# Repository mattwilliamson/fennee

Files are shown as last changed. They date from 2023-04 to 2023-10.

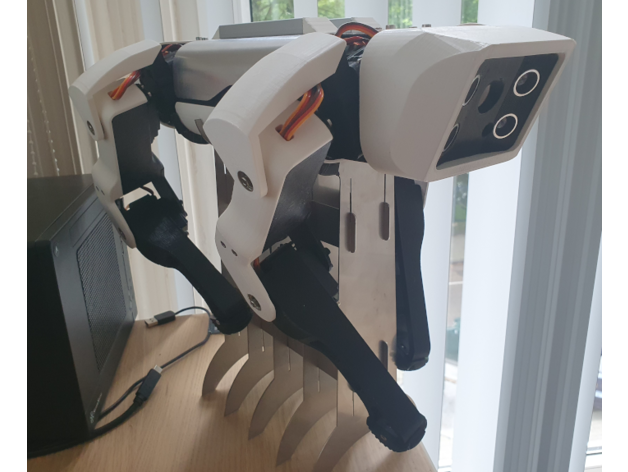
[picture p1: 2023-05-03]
models/SpotMicroESP32_with_reinforced_shoulders_4937631/images/featured_preview_saddled_with_shoulders.png

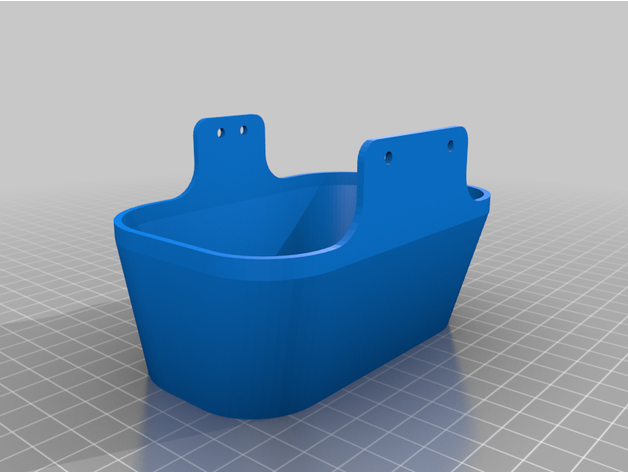
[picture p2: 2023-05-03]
models/SpotMicroESP32_with_reinforced_shoulders_4937631/images/Rear_Cover_Shell_Medium.png

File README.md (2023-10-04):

# Fennee Quadruped Robot

**F**oundation for **E**xperimental **N**eural **N**etwork **E**ndeavors

### Printing Video
Printing Fennee (http://www.youtube.com/watch?v=NxGy5EySv1w "Printing Fennee")

### Walking video
Fennee on the Run (http://www.youtube.com/watch?v=MeTuUr-WjSU "Fennee on the run")

---

# Hardware
Check the [Hardware & Parts Details docs](./docs/hardware.md)

# Software

- [Champ](https://github.com/chvmp/champ)
- [Ubuntu 20.04 Jetson Image](https://github.com/Qengineering/Jetson-Nano-Ubuntu-20-image) flashed on SD card with [Balena Etcher](https://www.balena.io/etcher)
- [ROS 1 Noetic](http://wiki.ros.org/noetic/Installation/Ubuntu)
- [Adafruit CircuitPython libraries](https://docs.circuitpython.org/projects/bundle/en/latest/drivers.html)
- [LDS-01 LIDAR ROS Driver](http://wiki.ros.org/hls_lfcd_lds_driver)

## Install Fennee Packages

First [Install ROS Noetic](./docs/install_ros.md)

**I'd like to switch to ROS2 when CHAMP finishes porting over**

```sh
# Source your ROS installation
source /opt/ros/noetic/setup.bash

# CD to your workspace source, e.g. ~/ros_ws and clone the repo
mkdir -p ~/ros_ws/src
cd ~/ros_ws/src
git clone https://github.com/mattwilliamson/fennee.git
vcs import < fennee/fennee_ros/fennee.rosinstall --recursive

# CD to your workspace and build
cd ..
rosdep install --from-paths src --ignore-src -r -y
catkin_make

# Source your build
source devel/setup.bash
```

## Running

TODO: Need to specify dependencies correctly

```sh

sudo pip3 install -t /opt/ros/noetic/lib/python3/dist-packages adafruit_blinka adafruit-circuitpython-servokit pyyaml
```

### Simulator

```sh
source devel/setup.bash
roslaunch fennee_config bringup.launch rviz:=true
```

```sh
source devel/setup.bash
roslaunch champ_teleop teleop.launch joy:=true
```

With a PS4/DS4 controller:

| Input | Output |
| --- | --- |
| Left Stick  | Walk/Yaw |
| Right Stick | Pitch/Roll |
| L1 (hold) | Holonomic (strafing) |
| R2 | Sit |

### Jetson Nano
```sh
ssh user@jetson
mkdir -p ~/ros_ws/src
cd ~/ros_ws/src

git clone https://github.com/mattwilliamson/fennee.git
cd fennee

sudo docker build -t fennee .
sudo docker run -it --rm --runtime nvidia --network host fennee
sudo docker run -it --rm --runtime nvidia -v $HOME/ros_ws/src/fennee:/fennee_ws/src/fennee --network host fennee

# Source your build
source devel/setup.bash
roslaunch fennee_config bringup.launch hardware_connected:=true
```

### Hardware

```sh
roslaunch fennee_config bringup.launch hardware_connected:=true

roslaunch champ_teleop teleop.launch joy:=true

rostopic echo joint_states
```

```sh
roslaunch fennee_config bringup.launch hardware_connected:=true
```

### Calibration

Start up a terminal GUI to set the servo offsets to a yaml file

```
roslaunch fennee_control servo_interface.launch calibrate:=true
```

```
rostopic echo servo_duty_cycles
```

Put duty cycles into `fennee_control/scripts/servo_interface.py` `pwm_map`.

fennee_config/config/gait/gait.yaml has `com_x_translation` to shift the center of balance from the front to the back. 
For example `-0.01` if the robot is leaning backwards a bit, keeping it from walking.

### Watching logs

GUI

```
rqt_console
```

### Credits
https://github.com/chvmp
https://github.com/michaelkubina/SpotMicroESP32
https://spotmicroai.readthedocs.io/en/latest/
https://www.thingiverse.com/thing:4937631

## TODO

- [ ] rewrite IMU in c++
- [ ] Make calibration launch file and parse yaml for servo_controller
- [ ] Calibration script docs
- [x] Update URDF with longer body
- [ ] Package requirements are a mess. pip vs rosdep etc.
- [ ] Charging connector
- [ ] Add clips to battery clips for wires
- [ ] Rear cover hole for voltmeter
- [x] Oak D Lite Camera mount
- [ ] LED Ring sticking out under lidar?
- [x] Separate mount for IMU
- [ ] Supports around holes for covers
- [x] Custom top and bottom cover, speakers, mic, fan
- [x] Lengthen chassis for more electronics room
- [x] Removable electronicts mount
- [x] Custom hip for metal servo arm
- [x] Custom mounting board for electronics
- [x] Custom nose for camera and LED ring
- [x] Lengthen body
- [x] New cover with lidar mount and fan
- [x] Front camera
- [ ] IMU Publisher
- [x] Faster baud rate
- [ ] Calibration config file
- [ ] Wiring diagrams
- [ ] 3d print instructions/list
- [ ] Show loading screen while robot is waiting for ROS
- [ ] LED ring
- [x] LIDAR
- [ ] Relay for servos
- [ ] Some kind of quick release for covers - removing battery is annoying
- [ ] Speakers/mic
- [ ] blacklist packages: ros-noetic-rosserial ros-noetic-rviz ros-noetic-gazebo-plugins

---

# Docker

https://hub.docker.com/_/ros/

Building the image
`LOW_MEM` is for lower memory systems, but takes longer.

```sh
sudo docker build --build-arg LOW_MEM=1 -t fennee .
```

ROS uses the ~/.ros/ directory for storing logs, and debugging info
```sh
docker run -v "/home/ubuntu/.ros/:/root/.ros/" -it --rm --network=host fennee
```

```sh
sudo docker run --rm -it -e ROS_IP=192.168.50.83 --privileged -v /dev/:/dev/ --network host fennee roslaunch fennee_config bringup.launch hardware_connected:=true
```

RViz/Gazebo
```sh
sudo docker run --rm -it -v /dev/:/dev/ --network host -e DISPLAY -v /tmp/.X11-unix:/tmp/.X11-unix --privileged depthai_ros roslaunch depthai_filters example_seg_overlay.launch
```

Camera publisher with overlay for object detection
```sh
sudo docker run --rm -it -e ROS_IP=192.168.50.83 --privileged -v /dev/:/dev/ --network host fennee roslaunch depthai_filters example_det2d_overlay.launch camera_model:=OAK-D-LITE
```

Camera publisher with stereo, RGB and IMU
```sh
sudo docker run --rm -it -e ROS_IP=192.168.50.83 --privileged -v /dev/:/dev/ --network host fennee roslaunch depthai_examples stereo_inertial_node.launch enableRviz:=false
```

View Camera
```sh
ROS_MASTER_URI=http://192.168.50.83:11311
rqt_image_view
```

Record Video to output.avi
```sh
fennee
ROS_MASTER_URI=http://192.168.50.83:11311 rosrun image_view video_recorder image:=/mobilenet_publisher/color/image
vlc output.avi
```

Mapping
```sh
ROS_MASTER_URI=http://192.168.50.83:11311
roslaunch fennee_config slam.launch rviz:=true  
```

Save map
```sh
roscd fennee_config/maps
rosrun map_server map_saver
```

Autonomous Navigation
```sh
roslaunch fennee_config navigate.launch rviz:=true
```

roslaunch champ_config slam.launch rviz:=true

roslaunch fennee_config navigate.launch

# PS4 Controller
*hold PS button and share button*

```
bluetoothctl
scan on
[NEW] Device A4:AE:12:BA:36:63 Wireless Controller

pair A4:AE:12:BA:36:63
trust A4:AE:12:BA:36:63
```

```sh
roslaunch fennee_config bringup.launch hardware_connected:=true
# roslaunch fennee_config bringup.launch hardware_connected:=true servo_connected:=false
roslaunch champ_teleop teleop.launch joy:=true
```

# IMU
http://docs.ros.org/en/melodic/api/robot_localization/html/preparing_sensor_data.html

sensor_msgs/Imu - The IMU message is currently subject to some ambiguity, though this is being addressed by the ROS community. Most IMUs natively report orientation data in a world-fixed frame whose axes are defined by the vectors pointing to magnetic north and the center of the earth, respectively, with the Y axis facing east (90 degrees offset from the magnetic north vector). This frame is often referred to as NED (North, East, Down). However, REP-103 specifies an ENU (East, North, Up) coordinate frame for outdoor navigation. As of this writing, robot_localization assumes an ENU frame for all IMU data, and does not work with NED frame data. This may change in the future, but for now, users should ensure that data is transformed to the ENU frame before using it with any node in robot_localization.

Measure +9.81
 meters per second squared for the Z
 axis.
If the sensor is rolled +90
 degrees (left side up), the acceleration should be +9.81
 meters per second squared for the Y
 axis.
If the sensor is pitched +90
 degrees (front side down), it should read -9.81
 meters per second squared for the X
 axis.

 The IMU may also be oriented on the robot in a position other than its “neutral” position. For example, the user may mount the IMU on its side, or rotate it so that it faces a direction other than the front of the robot. This offset is typically specified by a static transform from the base_link_frame parameter to the IMU message’s frame_id. The state estimation nodes in robot_localization will automatically correct for the orientation of the sensor so that its data aligns with the frame specified by the base_link_frame parameter.

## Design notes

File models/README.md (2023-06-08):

# 3d Printing Models
I printed everything in PETG except the feet in TPU

# michaelkubina_SpotMicroESP32
This is the primary source of parts. I customized some of these and found some customized ones.

# Outer_Shoulder_round_servohorn
The hip servohorn broke several times, so I updated the model to accept a round, metal servohorn.

# Chassis_Side_longer
Lengthened the body 25mm to accomodate a Jetson Nano and a larger buck converter.

# Circuitry_Mountingplate_jetson_nano

# metaldisc_servohorn_mod
under mods

# SpotMicroESP32_with_reinforced_shoulders_4937631
Reinforced shoulders by Rob Knegjens

Replaces a couple parts from SpotMicroESP32

Summary from Thingiverse https://www.thingiverse.com/thing:4937631

## Summary
This is a remix of Michael Kubina's SpotMicroESP32. It adds a reinforced shoulder joint cover as well as a shorter rear cover and back plate.

For the original SpotMicro the limbs connect to the shoulders only via the servo shaft, which in my experience made for a flimsy/wobbly joint. Reinforcing the joint with an extended shoulder attached to ball bearings on the outer limb improves this considerably.

My shoulder cover design was inspired by the Parametric Shoulder Joint for SpotMicroESP32 from projunk. Notable features are:

Uses 625ZZ ball bearings (as for the original).
The Shoulder Cover attaches to the extended Servo Cap using 3x20 mm screws and M3 nuts (as used by original build).
Hidden screw and nut holes on shoulder cover for a smooth look.
Prints support free.
The new medium rear cover is a shortened version of the long rear cover of the original build. The 3x8mm screws attaching the back plate are now rear facing. The back plate has cut-out inserts for a SSD1306 OLED screen and two GX16 connectors.

The spot shown in the photos has an aluminium top cover with mounting rails. This was made by Thomas Van Der Sterren.

## Print Settings
### Printer brand:
Creality

### Printer:
Ender 3 Pro

### Rafts:
No
### Supports:
No
### Resolution:
0.2 mm
### Infill:
20
### Filament brand:
REAL

### Filament color:
Black, White

### Filament material:
PLA, TPU

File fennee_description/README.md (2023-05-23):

# fennee_description

A minimal and revamped version of [SpotmicroAI](https://spotmicroai.readthedocs.io/en/latest/) description file pulled from its [Gitlab](https://gitlab.com/custom_robots/spotmicroai/simulation) repository.

The meshes' path have been modified so the models can be located using its package name.

## Quick Start

You can view the model by running:

    roslaunch fennee_description view_urdf.launch

## Testing

You can modify the Xacro description and see the changes in the UDF file with this command:

    rosrun xacro xacro fennee.urdf.xacro > fennee.urdf

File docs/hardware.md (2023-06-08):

# Hardware

## Parts List

- [SpotMicro](https://spotmicroai.readthedocs.io/en/latest/) robot frame
- [NVIDIA Jetson Nano](https://www.amazon.com/NVIDIA-Jetson-Nano-Developer-945-13450-0000-100/dp/B084DSDDLT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) for high-level control
- [SD Card](https://www.amazon.com/dp/B07FCMBLV6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)
- LDS-01 LIDAR
- USB TTL converter for LIDAR
- PCA9685 PWM controller for controlling servos: https://www.adafruit.com/product/815
- 12x [DS3218 Digital Servo Motor](https://www.amazon.com/gp/product/B07WYQ9P3F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)
- [LiPO Battery](https://www.amazon.com/dp/B086D71TZC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) this one is 5200mAh 7.4v, but you have flexibility here
- [Buck Converter](https://www.amazon.com/dp/B07Y7YB14L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)
- 2x [Bearings](https://www.amazon.com/dp/B07JHKKGKT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)
- [Lots](https://www.amazon.com/dp/B015A30R1I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) of [m3 screws and nuts (some m2 as well)](https://www.amazon.com/dp/B08JCKH31Q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)
- [PETG Filament](https://www.amazon.com/dp/B08JCKH31Q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)

*Disclaimer: I did add Amazon affiliate links to these*

### Optional

- [Waveshare AC8265](https://www.amazon.com/dp/B07SGDRG34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) WiFi and Bluetooth for Jetson Nano
- [IPEX Wifi Antennas](https://www.amazon.com/Antenna-2-4GHz-Internal-Laptop-Wireless/dp/B08XN6WMXJ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)
- [Volt Display](https://www.amazon.com/dp/B0761MG9NS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)
- [Creality Ender 3 S1 Pro 3d printer](https://www.amazon.com/3D-High-Temperature-Removable-Touchscreen-Languages/dp/B09TKCY9HY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)

## 3d Printed

- [SpotMicro prints without supports](https://www.thingiverse.com/thing:4559827)
- [Reinforced shoulders](https://www.thingiverse.com/thing:4937631)
- [Assembly Guide](https://github.com/mattwilliamson/SpotMicroESP32/tree/master/assembly) *Needs some updates*

---

## TODO Documentation

- [ ] Lidar specs - LDS-01 - https://emanual.robotis.com/docs/en/platform/turtlebot3/appendix_lds_01/ - https://medium.com/@Matthew_Hogan/interesting-electronic-components-1-hls-lfcd2-640d897f9fc9
- [ ] Oak D Lite - needs right angle cable

---

PCA9685 Connection
 - Connect VCC Pin of PCA9685 to 3.3 Volt Pin of Jetson Nano (Pin 1 upper outside)
 - Connect GND Pin of PCA9685 to Jetson Nano GND (Row 3, inside pin)
 - Connect SDA Pin of PCA9685 to Jetson Nano Pin 3 (Row 2, outside pin)
 - Connect SCL Pin of PCA9685 to Jetson Nano Pin 5 (Row 3, outside pin)

```
jetson@fennee:~/ros_ws$ sudo i2cdetect -y -r 1
     0  1  2  3  4  5  6  7  8  9  a  b  c  d  e  f
00:          -- -- -- -- -- -- -- -- -- -- -- -- -- 
10: -- -- -- -- -- -- -- -- -- -- -- -- -- -- -- -- 
20: -- -- -- -- -- -- -- -- -- -- -- -- -- -- -- -- 
30: -- -- -- -- -- -- -- -- -- -- -- -- -- -- -- -- 
40: 40 -- -- -- -- -- -- -- -- -- -- -- -- -- -- -- 
50: -- -- -- -- -- -- -- -- -- -- -- -- -- -- -- -- 
60: -- -- -- -- -- -- -- -- -- -- -- -- -- -- -- -- 
70: 70 -- -- -- -- -- -- --             
```

---

BNO085 IMU Connection

If you solder a header on the opposite side of the PCA9685, you can just daisy-chain onto that same I2C bus.

```
jetson@fennee:~/ros_ws/src/fennee$ i2cdetect -r -y 1
     0  1  2  3  4  5  6  7  8  9  a  b  c  d  e  f
00:          -- -- -- -- -- -- -- -- -- -- -- -- -- 
10: -- -- -- -- -- -- -- -- -- -- -- -- -- -- -- -- 
20: -- -- -- -- -- -- -- -- -- -- -- -- -- -- -- -- 
30: -- -- -- -- -- -- -- -- -- -- -- -- -- -- -- -- 
40: 40 -- -- -- -- -- -- -- -- -- -- 4b -- -- -- -- 
50: -- -- -- -- -- -- -- -- -- -- -- -- -- -- -- -- 
60: -- -- -- -- -- -- -- -- -- -- -- -- -- -- -- -- 
70: 70 -- -- -- -- -- -- --       
```

For mine, the address was 0x4b.

Testing:

```
$ sudo pip3 install adafruit-circuitpython-bno08x

$ python3
import board
import busio
import time
import adafruit_bno08x
from adafruit_bno08x.i2c import BNO08X_I2C
i2c = busio.I2C(board.SCL, board.SDA)
i2c.scan()
#bno = BNO08X_I2C(i2c)
bno = BNO08X_I2C(i2c, address=0x4b)
bno.enable_feature(BNO_REPORT_ACCELEROMETER)
bno.enable_feature(BNO_REPORT_GYROSCOPE)
bno.enable_feature(BNO_REPORT_MAGNETOMETER)
bno.enable_feature(BNO_REPORT_ROTATION_VECTOR)
while True:
     time.sleep(0.5)
     print("Acceleration:")
     accel_x, accel_y, accel_z = bno.acceleration  # pylint:disable=no-member
     print("X: %0.6f  Y: %0.6f Z: %0.6f  m/s^2" % (accel_x, accel_y, accel_z))
     print("")
     #
     print("Gyro:")
     gyro_x, gyro_y, gyro_z = bno.gyro  # pylint:disable=no-member
     print("X: %0.6f  Y: %0.6f Z: %0.6f rads/s" % (gyro_x, gyro_y, gyro_z))
     print("")
     #
     print("Magnetometer:")
     mag_x, mag_y, mag_z = bno.magnetic  # pylint:disable=no-member
     print("X: %0.6f  Y: %0.6f Z: %0.6f uT" % (mag_x, mag_y, mag_z))
     print("")
     #
     print("Rotation Vector Quaternion:")
     quat_i, quat_j, quat_k, quat_real = bno.quaternion  # pylint:disable=no-member
     print(
      "I: %0.6f  J: %0.6f K: %0.6f  Real: %0.6f" % (quat_i, quat_j, quat_k, quat_real)
     )
     print("")
```

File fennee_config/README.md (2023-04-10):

## 1. Quick Start

You don't need a physical robot to run the following demos. 

### 1.1. Walking demo in RVIZ:

#### 1.1.1. Run the base driver:

    roslaunch fennee_config bringup.launch rviz:=true

#### 1.1.2. Run the teleop node:

    roslaunch champ_teleop teleop.launch

If you want to use a [joystick](https://www.logitechg.com/en-hk/products/gamepads/f710-wireless-gamepad.html) add joy:=true as an argument.

### 1.2. SLAM demo:

#### 1.2.1. Run the Gazebo environment:

    roslaunch fennee_config gazebo.launch 

#### 1.2.2. Run gmapping package and move_base:

    roslaunch fennee_config slam.launch rviz:=true

To start mapping:

- Click '2D Nav Goal'.
- Click and drag at the position you want the robot to go.

   champ

- Save the map by running:

      roscd fennee_config/maps
      rosrun map_server map_saver

### 1.3. Autonomous Navigation:

#### 1.3.1. Run the Gazebo environment: 

    roslaunch fennee_config gazebo.launch 

#### 1.3.2. Run amcl and move_base:

    roslaunch fennee_config navigate.launch rviz:=true

To navigate:

- Click '2D Nav Goal'.
- Click and drag at the position you want the robot to go.

   champ

#### 1.4.1 Spawning multiple robots in Gazebo

Run Gazebo and default simulation world:

    roslaunch champ_gazebo spawn_world.launch 

You can also load your own world file by passing your world's path to 'gazebo_world' argument:

    roslaunch champ_gazebo spawn_world.launch gazebo_world:=<path_to_world_file>

Spawning a robot:

    roslaunch fennee_config spawn_robot.launch robot_name:=<unique_robot_name> world_init_x:=<x_position> world_init_y:=<y_position>

* Every instance of the spawned robot must have a unique robot name to prevent the topics and transforms from clashing.

---
:exclamation: *This is not an official product from the robot's company/author.*

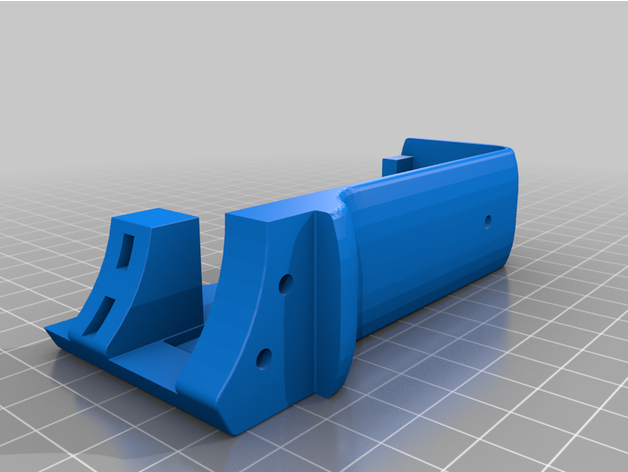
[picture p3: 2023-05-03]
models/SpotMicroESP32_with_reinforced_shoulders_4937631/images/Limb_Top_Shell_with_BB_hole.png

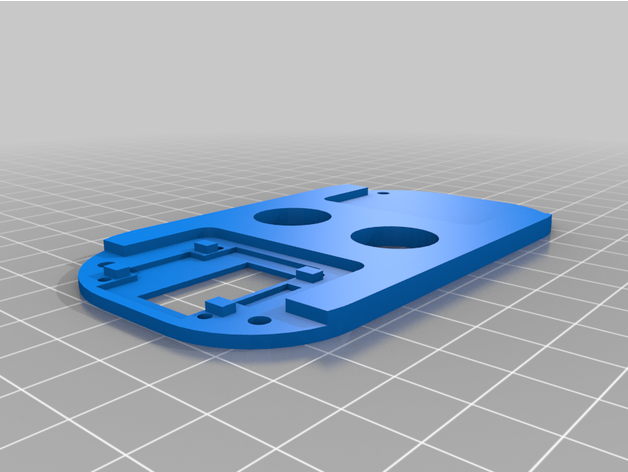
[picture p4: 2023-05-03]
models/SpotMicroESP32_with_reinforced_shoulders_4937631/images/Rear_Cover_Plate_Medium.png

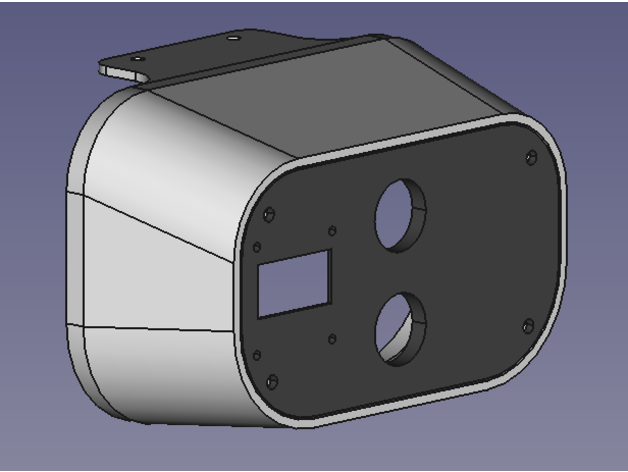
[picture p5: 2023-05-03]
models/SpotMicroESP32_with_reinforced_shoulders_4937631/images/featured_preview_RearCAD2.png

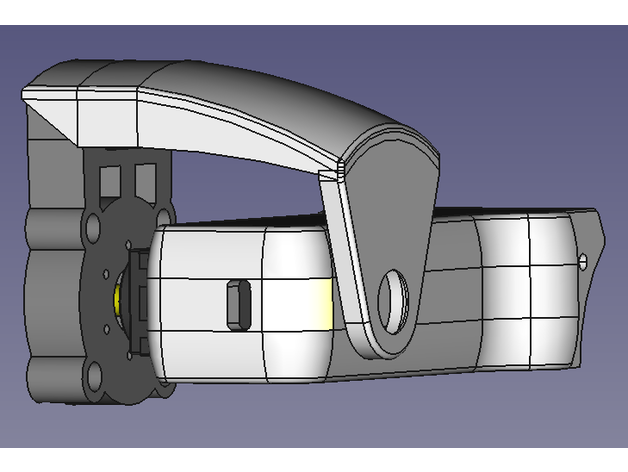
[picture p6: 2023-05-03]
models/SpotMicroESP32_with_reinforced_shoulders_4937631/images/featured_preview_ShoulderCAD1.png

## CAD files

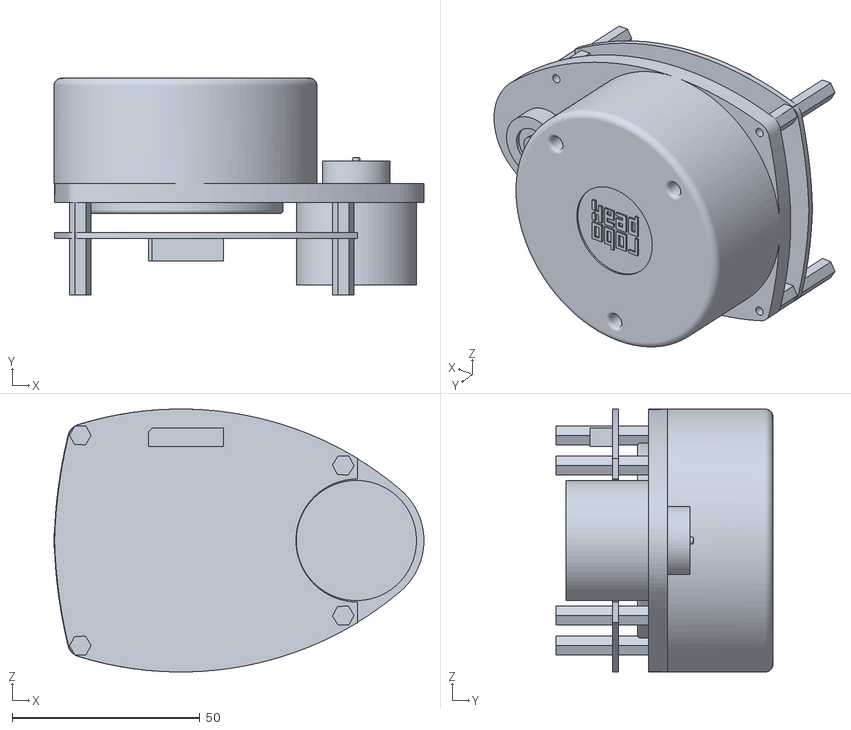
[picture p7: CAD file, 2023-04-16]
fennee_description/meshes/stl/rplidar_main.STL
98.5 x 57.7 x 70.0

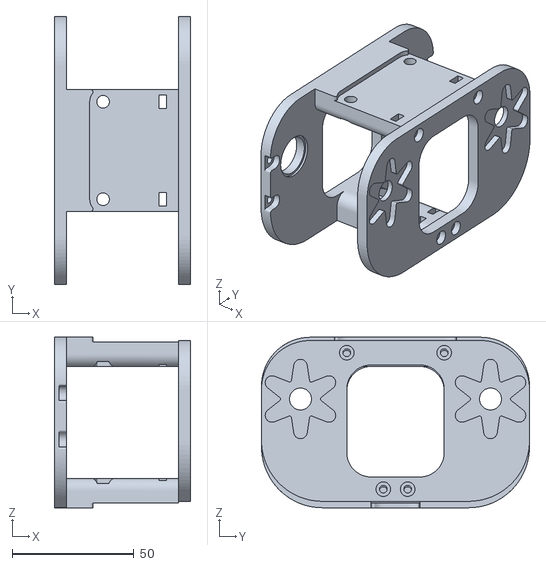
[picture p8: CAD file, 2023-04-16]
fennee_description/meshes/stl/rearmain.stl
55.9 x 110.0 x 70.0

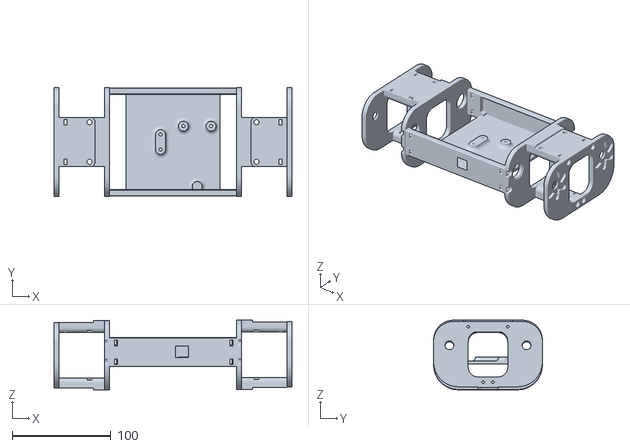
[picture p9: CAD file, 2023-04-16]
fennee_description/meshes/stl/mainbody.stl
240.7 x 110.0 x 70.4

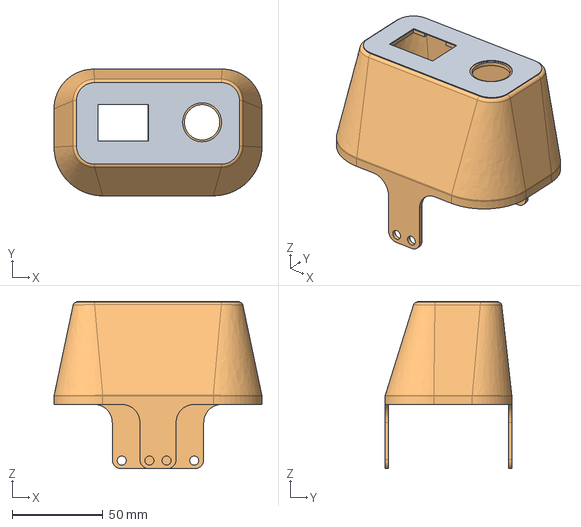
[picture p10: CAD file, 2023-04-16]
fennee_description/meshes/FreeCAD/SpotMicroAI_Rear.FCStd
114.8 x 70.0 x 92.4 mm
rearlabel
Rear

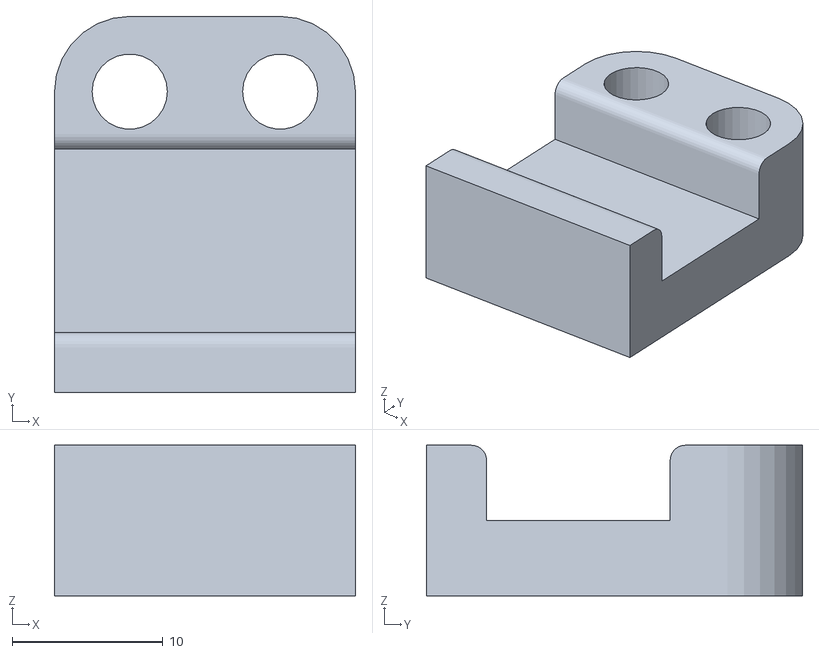
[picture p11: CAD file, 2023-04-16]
fennee_description/meshes/stl/testmount.stl
20.0 x 25.0 x 10.0

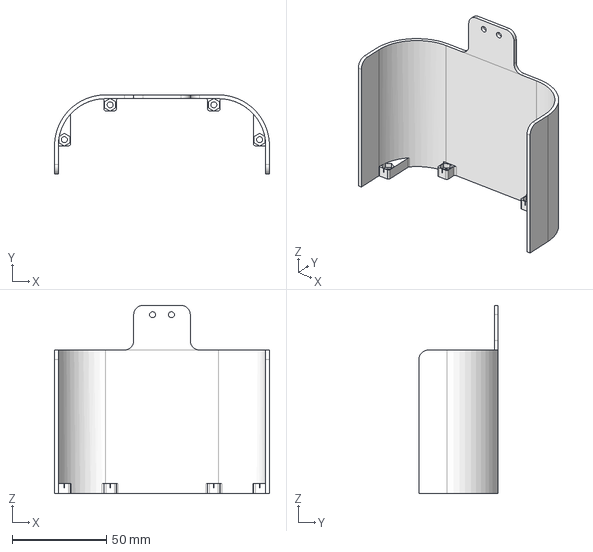
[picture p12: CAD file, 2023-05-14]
models/bottom_cover/Bottom_Cover_Split_Front.FCStd
114.0 x 42.0 x 99.9 mm

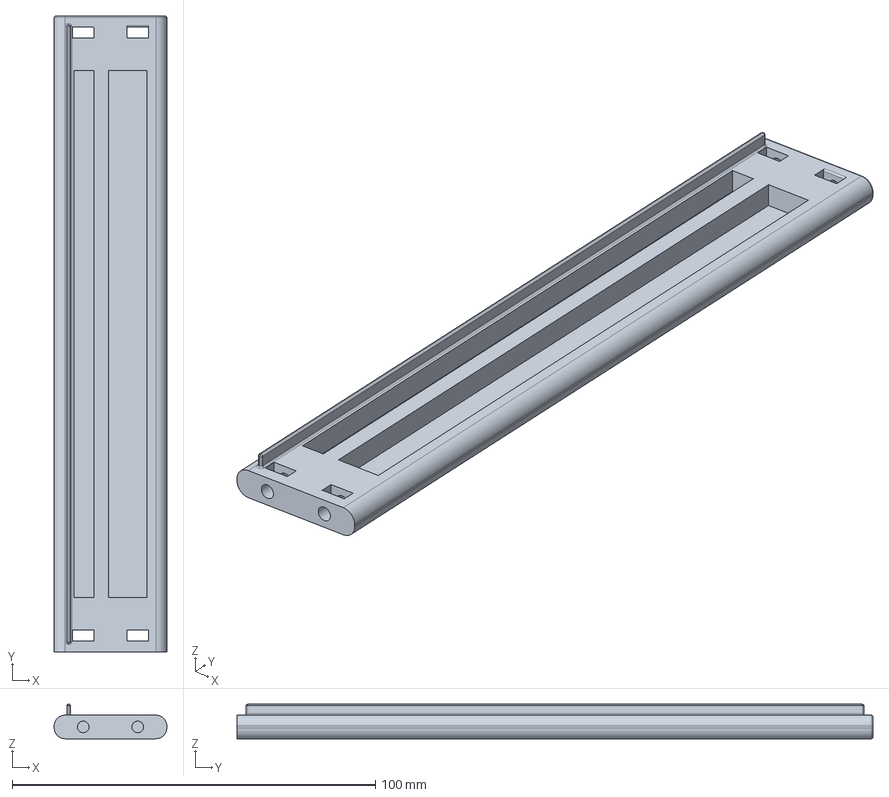
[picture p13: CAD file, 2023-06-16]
models/Chassis_Side_longer/Chassis_Side_longer.FCStd
31.0 x 175.0 x 9.50 mm

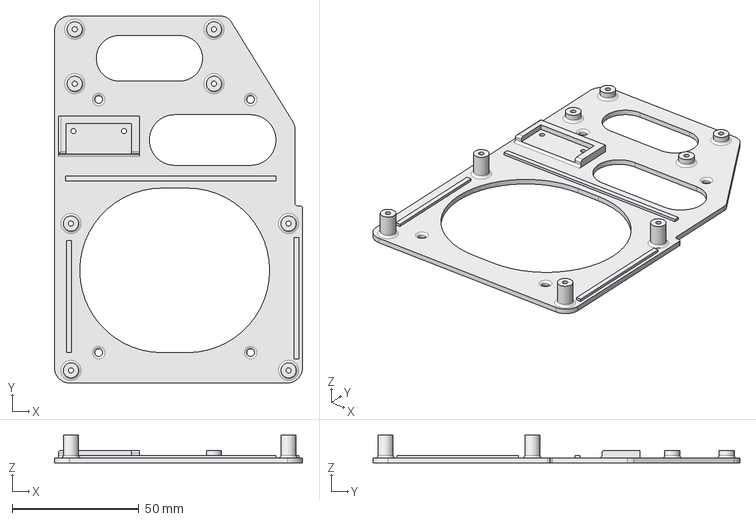
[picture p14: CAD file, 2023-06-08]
models/circuit_carrier/circuit_carrier.FCStd
98.0 x 145.0 x 11.0 mm

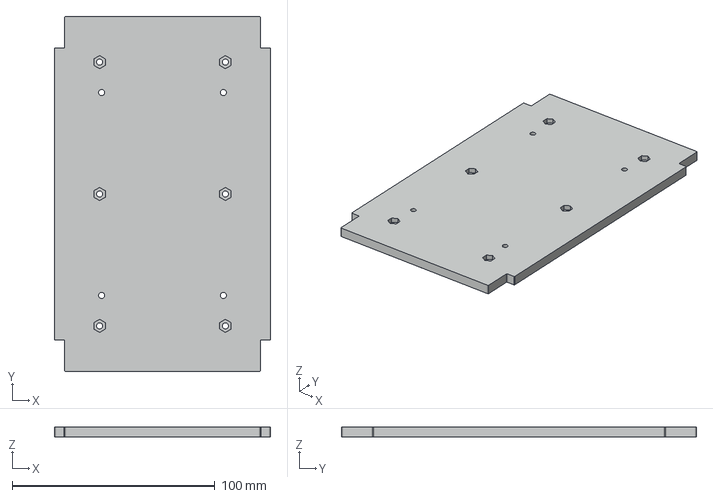
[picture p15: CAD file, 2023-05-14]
models/Circuitry_Mountingplate_modular/Circuitry_Mountingplate_modular.FCStd
106.5 x 175.0 x 5.00 mm

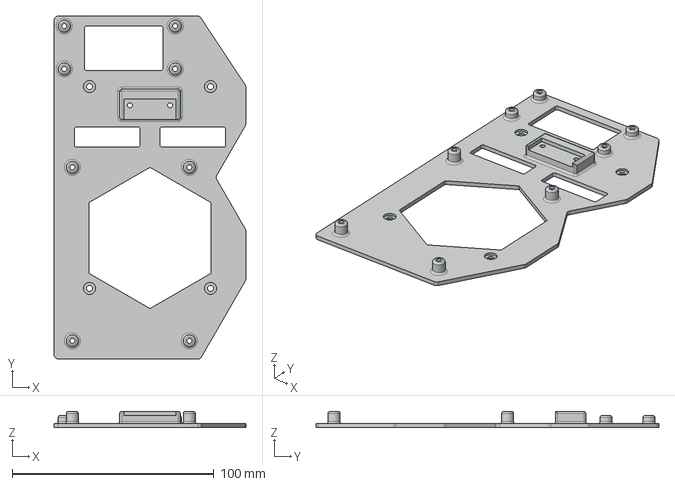
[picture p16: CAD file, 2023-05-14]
models/Circuitry_Mountingplate_standoffs/Circuitry_Mountingplate_standoffs.FCStd
95.0 x 170.0 x 8.00 mm

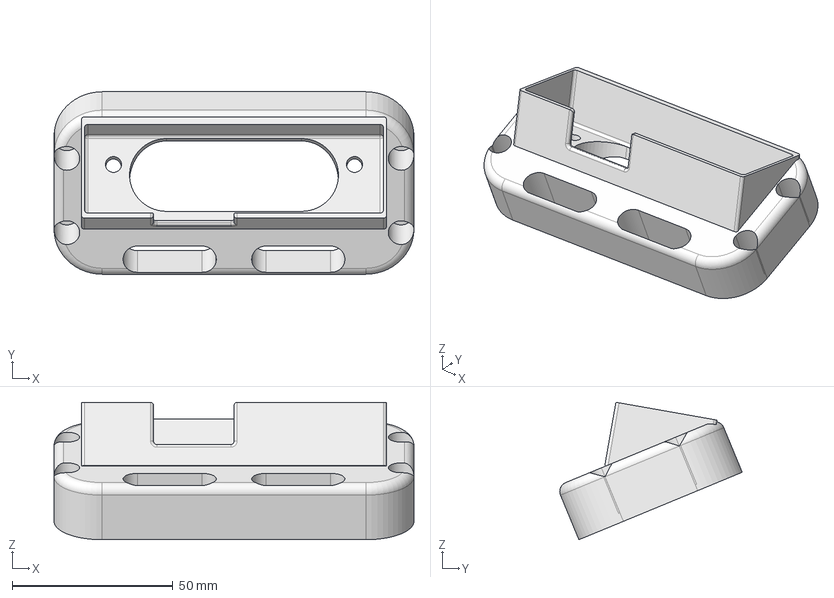
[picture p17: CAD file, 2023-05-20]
models/face/oakdlite_plate.FCStd
112.0 x 56.8 x 42.8 mm

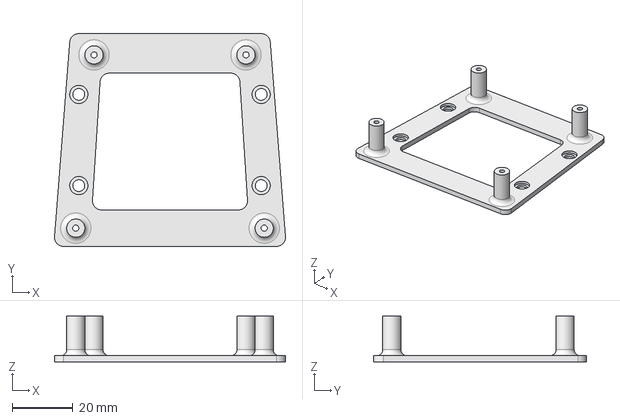
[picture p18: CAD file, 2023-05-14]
models/hitachi_lg_lidar_mount/hitachi_lg_lidar_mount.FCStd
76.0 x 70.0 x 15.0 mm

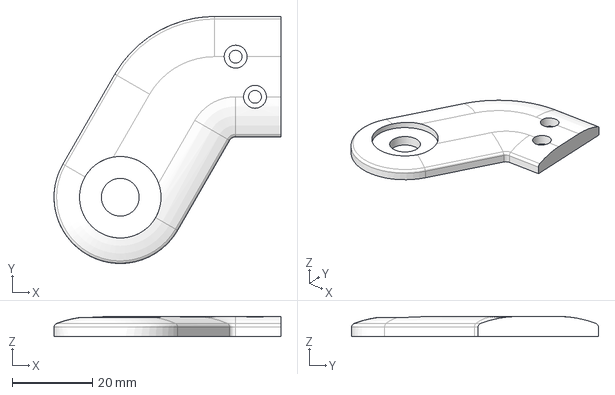
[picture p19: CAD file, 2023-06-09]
models/Limb_Round_Servohorn_Mount/Limb_Servohorn_Mount_long_v4.FCStd
56.5 x 61.5 x 5.00 mm

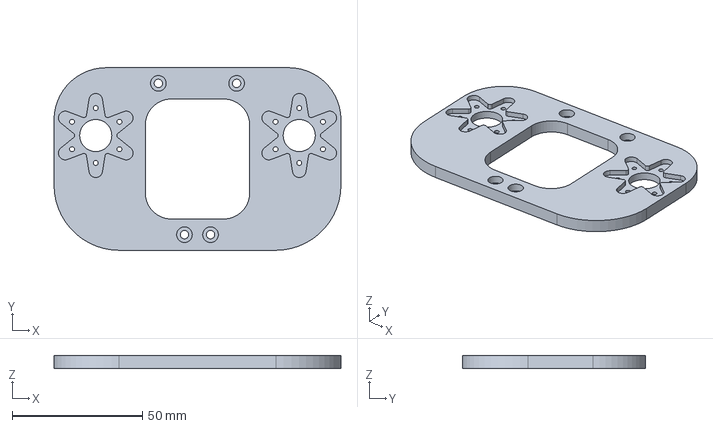
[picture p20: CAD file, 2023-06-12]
models/Outer_Shoulder_round_servohorn/Outer_Shoulder_round_servohorn.FCStd
110.0 x 70.0 x 5.00 mm

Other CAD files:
models/Rear_Cover/Rear_Cover_Shell_Medium.FCStd
models/SpotMicroESP32_with_reinforced_shoulders_4937631/files/Shoulder_Joint_Servomount_extended_BB.stl
models/top_cover/top_cover_back.stl
models/Wrist_35kg_servo/Wrist.FCStd
fennee_description/meshes/FreeCAD/SpotMicroAI_AdditionalParts.FCStd
fennee_description/meshes/FreeCAD/SpotMicroAI_Bottom.FCStd
fennee_description/meshes/FreeCAD/SpotMicroAI_JetsonParts.FCStd
fennee_description/meshes/FreeCAD/SpotMicroAI_Top.FCStd
fennee_description/meshes/stl/B_cover.stl
fennee_description/meshes/stl/F_cover.stl
fennee_description/meshes/stl/F_cover_orig.stl
fennee_description/meshes/stl/F_shoulder.stl
fennee_description/meshes/stl/L_arm.stl
fennee_description/meshes/stl/L_arm_cover.stl
fennee_description/meshes/stl/L_arm_joint.stl
fennee_description/meshes/stl/L_side_plate.stl
fennee_description/meshes/stl/L_ultra_sonic.stl
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

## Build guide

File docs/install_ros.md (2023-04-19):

# Install ROS Noetic on Ubuntu 20.04

From http://wiki.ros.org/noetic/Installation/Ubuntu

```sh
ssh jetson@nano

# Let's update and upgrade everything first
sudo apt-get update
sudo apt-get upgrade -y

# Expand root partition to use up entire SD card
sudo apt-get install -y gparted
gparted

# Install ROS
sudo sh -c 'echo "deb http://packages.ros.org/ros/ubuntu $(lsb_release -sc) main" > /etc/apt/sources.list.d/ros-latest.list'
sudo apt-get install -y curl
curl -s https://raw.githubusercontent.com/ros/rosdistro/master/ros.asc | sudo apt-key add -
sudo apt-get update
# sudo apt-get install -y ros-noetic-desktop-full
sudo apt-get install -y \
        ros-noetic-desktop \
        python3-rosdep \
        python3-rosinstall \
        python3-rosinstall-generator \
        python3-wstool \
        python3-vcstool \
        build-essential \
        ros-noetic-ecl-threads \
        ros-noetic-vision-msgs \
        ros-noetic-image-transport \
        ros-noetic-tf \
        ros-noetic-urdf \
        ros-noetic-ecl-threads \
        ros-noetic-robot-state-publisher \
        ros-noetic-robot-localization \
        ros-noetic-controller-manager \
        ros-noetic-joy

echo "source /opt/ros/noetic/setup.bash" >> ~/.bashrc
source ~/.bashrc

sudo rosdep init
rosdep update

```

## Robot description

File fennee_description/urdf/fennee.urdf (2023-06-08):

<?xml version="1.0" ?>
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
<robot name="fennee">
  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
  <link name="base_link"/>
  <link name="base_inertia">
    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
    <inertial>
      <mass value="3.4"/>
      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
    </inertial>
  </link>
  <joint name="base_inertia_joint" type="fixed">
    <parent link="base_link"/>
    <child link="base_inertia"/>
  </joint>
  <link name="rear_link">
    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
    <inertial>
      <mass value="0.20"/>
      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
    </inertial>
  </link>
  <joint name="base_rear" type="fixed">
    <parent link="base_link"/>
    <child link="rear_link"/>
  </joint>
  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
  <link name="front_link">
    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
    <inertial>
      <mass value="0.20"/>
      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
    </inertial>
  </link>
  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
  <joint name="base_front" type="fixed">
    <parent link="base_link"/>
    <child link="front_link"/>
  </joint>
  <link name="front_left_shoulder_link">
    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
    <inertial>
      <mass value="0.10"/>
      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
    </inertial>
  </link>
  <link name="front_left_leg_link_cover">
    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
  </link>
  <link name="front_left_leg_link">
    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
    <inertial>
      <mass value="0.15"/>
      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
    </inertial>
  </link>
  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
  <link name="front_left_foot_link">
    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
    <inertial>
      <mass value="0.1"/>
      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
    </inertial>
  </link>
  <link name="front_left_toe_link">
    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
    <inertial>
      <mass value="0.05"/>
      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
    </inertial>
  </link>
  <joint name="front_left_shoulder" type="revolute">
    <parent link="base_link"/>
    <child link="front_left_shoulder_link"/>
    <axis xyz="1 0 0"/>
    <origin rpy="0 0 0" xyz="0.093 0.04285 0"/>
    <limit effort="1000.0" lower="-0.548" upper="0.548" velocity="0.7"/>
    <dynamics damping="0.0" friction="0.5"/>
  </joint>
  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
  <joint name="front_left_leg" type="revolute">
    <parent link="front_left_shoulder_link"/>
    <child link="front_left_leg_link"/>
    <axis xyz="0 1 0"/>
    <origin rpy="0 0 0" xyz="0 0.055 0"/>
    <limit effort="1000.0" lower="-2.666" upper="1.548" velocity="0.5"/>
    <dynamics damping="0.0" friction="0.0"/>
  </joint>
  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
  <joint name="front_left_leg_cover_joint" type="fixed">
    <parent link="front_left_leg_link"/>
    <child link="front_left_leg_link_cover"/>
    <origin xyz="0 0 0"/>
  </joint>
  <joint name="front_left_foot" type="revolute">
    <parent link="front_left_leg_link"/>
    <child link="front_left_foot_link"/>
    <axis xyz="0 1 0"/>
    <origin rpy="0 0 0" xyz="0.014 0 -0.109"/>
    <limit effort="1000.0" lower="-2.59" upper="0.1" velocity="0.5"/>
    <dynamics damping="0.0" friction="0.5"/>
  </joint>
  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
  <joint name="front_left_toe" type="fixed">
    <parent link="front_left_foot_link"/>
    <child link="front_left_toe_link"/>
    <origin xyz="0 0 -0.13"/>
  </joint>
  <link name="front_right_shoulder_link">
    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
    <inertial>
      <mass value="0.10"/>
      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
    </inertial>
  </link>
  <link name="front_right_leg_link_cover">
    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
  </link>
  <link name="front_right_leg_link">
    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
    <inertial>
      <mass value="0.15"/>
      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
    </inertial>
  </link>
  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
  <link name="front_right_foot_link">
    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
    <inertial>
      <mass value="0.1"/>
      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
    </inertial>
  </link>
  <link name="front_right_toe_link">
    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
    <inertial>
      <mass value="0.05"/>
      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
    </inertial>
  </link>
  <joint name="front_right_shoulder" type="revolute">
    <parent link="base_link"/>
    <child link="front_right_shoulder_link"/>
    <axis xyz="1 0 0"/>
    <origin rpy="0 0 0" xyz="0.093 -0.04285 0"/>
    <limit effort="1000.0" lower="-0.548" upper="0.548" velocity="0.7"/>
    <dynamics damping="0.0" friction="0.5"/>
  </joint>
  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
  <joint name="front_right_leg" type="revolute">
    <parent link="front_right_shoulder_link"/>
    <child link="front_right_leg_link"/>
    <axis xyz="0 1 0"/>
    <origin rpy="0 0 0" xyz="0 -0.055 0"/>
    <limit effort="1000.0" lower="-2.666" upper="1.548" velocity="0.5"/>
    <dynamics damping="0.0" friction="0.0"/>
  </joint>
  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
  <joint name="front_right_leg_cover_joint" type="fixed">
    <parent link="front_right_leg_link"/>
    <child link="front_right_leg_link_cover"/>
    <origin xyz="0 0 0"/>
  </joint>
  <joint name="front_right_foot" type="revolute">
    <parent link="front_right_leg_link"/>
    <child link="front_right_foot_link"/>
    <axis xyz="0 1 0"/>
    <origin rpy="0 0 0" xyz="0.014 0 -0.109"/>
    <limit effort="1000.0" lower="-2.59" upper="0.1" velocity="0.5"/>
    <dynamics damping="0.0" friction="0.5"/>
  </joint>
  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
  <joint name="front_right_toe" type="fixed">
    <parent link="front_right_foot_link"/>
    <child link="front_right_toe_link"/>
    <origin xyz="0 0 -0.13"/>
  </joint>
  <link name="rear_left_shoulder_link">
    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
    <inertial>
      <mass value="0.10"/>
      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
    </inertial>
  </link>
  <link name="rear_left_leg_link_cover">
    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
  </link>
  <link name="rear_left_leg_link">
    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
    <inertial>
      <mass value="0.15"/>
      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
    </inertial>
  </link>
  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
  <link name="rear_left_foot_link">
    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
    <inertial>
      <mass value="0.1"/>
      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
    </inertial>
  </link>
  <link name="rear_left_toe_link">
    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
    <inertial>
      <mass value="0.05"/>
      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
    </inertial>
  </link>
  <joint name="rear_left_shoulder" type="revolute">
    <parent link="base_link"/>
    <child link="rear_left_shoulder_link"/>
    <axis xyz="1 0 0"/>
    <origin rpy="0 0 0" xyz="-0.093 0.04285 0"/>
    <limit effort="1000.0" lower="-0.548" upper="0.548" velocity="0.7"/>
    <dynamics damping="0.0" friction="0.5"/>
  </joint>
  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
  <joint name="rear_left_leg" type="revolute">
    <parent link="rear_left_shoulder_link"/>
    <child link="rear_left_leg_link"/>
    <axis xyz="0 1 0"/>
    <origin rpy="0 0 0" xyz="0 0.055 0"/>
    <limit effort="1000.0" lower="-2.666" upper="1.548" velocity="0.5"/>
    <dynamics damping="0.0" friction="0.0"/>
  </joint>
  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
  <joint name="rear_left_leg_cover_joint" type="fixed">
    <parent link="rear_left_leg_link"/>
    <child link="rear_left_leg_link_cover"/>
    <origin xyz="0 0 0"/>
  </joint>
  <joint name="rear_left_foot" type="revolute">
    <parent link="rear_left_leg_link"/>
    <child link="rear_left_foot_link"/>
    <axis xyz="0 1 0"/>
    <origin rpy="0 0 0" xyz="0.014 0 -0.109"/>
    <limit effort="1000.0" lower="-2.59" upper="0.1" velocity="0.5"/>
    <dynamics damping="0.0" friction="0.5"/>
  </joint>
  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
  <joint name="rear_left_toe" type="fixed">
    <parent link="rear_left_foot_link"/>
    <child link="rear_left_toe_link"/>
    <origin xyz="0 0 -0.13"/>
  </joint>
  <link name="rear_right_shoulder_link">
    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
    <inertial>
      <mass value="0.10"/>
      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
    </inertial>
  </link>
  <link name="rear_right_leg_link_cover">
    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
  </link>
  <link name="rear_right_leg_link">
    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
    <inertial>
      <mass value="0.15"/>
      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
    </inertial>
  </link>
  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
  <link name="rear_right_foot_link">
    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
    <inertial>
      <mass value="0.1"/>
      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
    </inertial>
  </link>
  <link name="rear_right_toe_link">
    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
    <inertial>
      <mass value="0.05"/>
      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
    </inertial>
  </link>
  <joint name="rear_right_shoulder" type="revolute">
    <parent link="base_link"/>
    <child link="rear_right_shoulder_link"/>
    <axis xyz="1 0 0"/>
    <origin rpy="0 0 0" xyz="-0.093 -0.04285 0"/>
    <limit effort="1000.0" lower="-0.548" upper="0.548" velocity="0.7"/>
    <dynamics damping="0.0" friction="0.5"/>
  </joint>
  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
  <joint name="rear_right_leg" type="revolute">
    <parent link="rear_right_shoulder_link"/>
    <child link="rear_right_leg_link"/>
    <axis xyz="0 1 0"/>
    <origin rpy="0 0 0" xyz="0 -0.055 0"/>
    <limit effort="1000.0" lower="-2.666" upper="1.548" velocity="0.5"/>
    <dynamics damping="0.0" friction="0.0"/>
  </joint>
  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
  <joint name="rear_right_leg_cover_joint" type="fixed">
    <parent link="rear_right_leg_link"/>
    <child link="rear_right_leg_link_cover"/>
    <origin xyz="0 0 0"/>
  </joint>
  <joint name="rear_right_foot" type="revolute">
    <parent link="rear_right_leg_link"/>
    <child link="rear_right_foot_link"/>
    <axis xyz="0 1 0"/>
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

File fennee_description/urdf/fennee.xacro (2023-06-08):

<?xml version="1.0" encoding="UTF-8"?>
<robot xmlns:xacro="http://www.ros.org/wiki/xacro" name="fennee">
   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
   <xacro:property name="body_length" value="0.165" />
   <xacro:property name="body_width" value="0.110" />
   <xacro:property name="body_height" value="0.070" />
   <xacro:property name="lidar_length" value="0.0985" />
   <xacro:property name="lidar_width" value="0.0577" />
   <xacro:property name="lidar_height" value="0.070" />
   <xacro:property name="front_length" value="0.058" />
   <xacro:property name="rear_length" value="0.040" />
   <xacro:property name="shoulder_length" value="0.044" />
   <xacro:property name="shoulder_width" value="0.038" />
   <xacro:property name="leg_length" value="0.109" />
   <xacro:property name="foot_length" value="0.13" />
   <xacro:property name="toe_radius" value="0.020" />
   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
   <xacro:property name="toe_width" value="0.020" />
   <xacro:property name="shift" value="0.055" />
   <xacro:property name="shiftx" value="0.093" />
   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
   <xacro:property name="shifty" value="0.04285" />

   <xacro:property name="has_imu" value="true" />
   <xacro:property name="imu_offset_x" value="0.0" />
   <xacro:property name="imu_offset_y" value="-0.15" />
   <xacro:property name="imu_offset_z" value="-0.04" />
   <xacro:property name="imu_r" value="0" />
   <xacro:property name="imu_p" value="0" />
   <xacro:property name="imu_y" value="-1.570795" />
   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
   <xacro:macro name="gen_shoulder" params="name left">
      <link name="${name}">
         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
         <inertial>
            <mass value="0.10" />
            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
         </inertial>
      </link>
   </xacro:macro>
   <xacro:macro name="gen_shoulder_joint" params="pos shiftx shifty">
      <joint name="${pos}_shoulder" type="revolute">
         <parent link="base_link" />
         <child link="${pos}_shoulder_link" />
         <axis xyz="1 0 0" />
         <origin rpy="0 0 0" xyz="${shiftx} ${shifty} 0" />
         <limit effort="1000.0" velocity="0.7" lower="-0.548" upper="0.548" />
         <dynamics damping="0.0" friction="0.5" />
      </joint>
      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
   </xacro:macro>
   <xacro:macro name="gen_leg" params="name left">
      <link name="${name}_cover">
         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
      </link>
      <link name="${name}">
         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
         <inertial>
            <mass value="0.15" />
            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
         </inertial>
      </link>
      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
   </xacro:macro>
   <xacro:macro name="gen_leg_joint" params="pos shift">
      <joint name="${pos}_leg" type="revolute">
         <parent link="${pos}_shoulder_link" />
         <child link="${pos}_leg_link" />
         <axis xyz="0 1 0" />
         <origin rpy="0 0 0" xyz="0 ${shift} 0" />
         <limit effort="1000.0" velocity="0.5" lower="-2.666" upper="1.548" />
         <dynamics damping="0.0" friction="0.0" />
      </joint>
      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
      <joint name="${pos}_leg_cover_joint" type="fixed">
         <parent link="${pos}_leg_link" />
         <child link="${pos}_leg_link_cover" />
         <origin xyz="0 0 0" />
      </joint>
   </xacro:macro>
   <xacro:macro name="gen_foot" params="name left">
      <link name="${name}">
         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
         <inertial>
            <mass value="0.1" />
            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
         </inertial>
      </link>
   </xacro:macro>
   <xacro:macro name="gen_foot_joint" params="pos">
      <joint name="${pos}_foot" type="revolute">
         <parent link="${pos}_leg_link" />
         <child link="${pos}_foot_link" />
         <axis xyz="0 1 0" />
         <origin rpy="0 0 0" xyz="0.014 0 -${leg_length}" />
         <limit effort="1000.0" velocity="0.5" lower="-2.59" upper="0.1" />
         <dynamics damping="0.0" friction="0.5" />
      </joint>
      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
   </xacro:macro>
   <xacro:macro name="gen_toe" params="name">
      <link name="${name}">
         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
         <inertial>
            <mass value="0.05" />
            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
         </inertial>
      </link>
   </xacro:macro>
   <xacro:macro name="gen_toe_joint" params="pos">
      <joint name="${pos}_toe" type="fixed">
         <parent link="${pos}_foot_link" />
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

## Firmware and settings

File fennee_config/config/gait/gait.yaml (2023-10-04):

knee_orientation : ">>"
pantograph_leg : false
odom_scaler: 1.0
max_linear_velocity_x : 0.5
max_linear_velocity_y : 0.25
max_angular_velocity_z : 1.0
com_x_translation : -0.027
swing_height : 0.02
stance_depth : 0.0
stance_duration : 0.25
nominal_height : 0.18


# open quadruped
# odom_scaler: 1.15
# max_linear_velocity_x : 0.3
# max_linear_velocity_y : 0.15
# max_angular_velocity_z : 1.0
# com_x_translation : -0.03
# swing_height : 0.02
# stance_depth : 0.0
# stance_duration : 0.25
# nominal_height : 0.15

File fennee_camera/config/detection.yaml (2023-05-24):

/oak:
    camera_i_enable_imu: true
    camera_i_enable_ir: true
    camera_i_floodlight_brightness: 0.0
    camera_i_ip: ''
    camera_i_laser_dot_brightness: 800.0
    camera_i_mx_id: ''
    camera_i_nn_type: spatial
    camera_i_pipeline_type: RGBD
    camera_i_usb_port_id: ''
    camera_i_usb_speed: SUPER_PLUS
    imu_i_max_q_size: 30
    left_i_board_socket_id: 1
    left_i_calibration_file: ''
    left_i_fps: 15.0
    left_i_height: 480
    left_i_low_bandwidth: false
    left_i_low_bandwidth_quality: 50
    left_i_max_q_size: 30
    left_i_preview_size: 300
    left_i_publish_topic: false
    left_i_resolution: '480'
    left_i_set_isp_scale: false
    left_i_width: 640
    left_r_exposure: 1000
    left_r_focus: 1
    left_r_iso: 800
    left_r_keep_preview_aspect_ratio: true
    left_r_set_man_exposure: false
    left_r_set_man_focus: false
    left_r_set_man_whitebalance: false
    left_r_whitebalance: 3300
    nn_i_nn_config_path: depthai_ros_driver/mobilenet
    rgb_i_board_socket_id: 0
    rgb_i_calibration_file: ''
    rgb_i_enable_preview: false
    rgb_i_fps: 30.0
    rgb_i_height: 720
    rgb_i_interleaved: false
    rgb_i_keep_preview_aspect_ratio: true
    rgb_i_low_bandwidth: false
    rgb_i_low_bandwidth_quality: 50
    rgb_i_max_q_size: 30
    rgb_i_preview_size: 300
    rgb_i_publish_topic: true
    rgb_i_resolution: '1080'
    rgb_i_set_isp_scale: true
    rgb_i_output_isp: true
    rgb_i_width: 1280
    rgb_r_exposure: 1000
    rgb_r_focus: 1
    rgb_r_iso: 800
    rgb_r_keep_preview_aspect_ratio: true
    rgb_r_set_man_exposure: false
    rgb_r_set_man_focus: false
    rgb_r_set_man_whitebalance: false
    rgb_r_whitebalance: 3300
    rgb_i_isp_num: 2
    rgb_i_isp_den: 3
    right_i_board_socket_id: 2
    right_i_calibration_file: ''
    right_i_fps: 30.0
    right_i_height: 480
    right_i_low_bandwidth: false
    right_i_low_bandwidth_quality: 50
    right_i_max_q_size: 30
    right_i_preview_size: 300
    right_i_publish_topic: false
    right_i_resolution: '480'
    right_i_set_isp_scale: false
    right_i_width: 640
    right_r_exposure: 1000
    right_r_focus: 1
    right_r_iso: 800
    right_r_keep_preview_aspect_ratio: true
    right_r_set_man_exposure: false
    right_r_set_man_focus: false
    right_r_set_man_whitebalance: false
    right_r_whitebalance: 3300
    stereo_i_align_depth: true
    stereo_i_bilateral_sigma: 0
    stereo_i_board_socket_id: 0
    stereo_i_calibration_file: ''
    stereo_i_decimation_filter_decimation_factor: 1
    stereo_i_decimation_filter_decimation_mode: PIXEL_SKIPPING
    stereo_i_depth_filter_size: 5
    stereo_i_depth_preset: HIGH_ACCURACY
    stereo_i_enable_decimation_filter: false
    stereo_i_enable_distoartion_correction: false
    stereo_i_enable_spatial_filter: false
    stereo_i_enable_temporal_filter: false
    stereo_i_enable_threshold_filter: false
    stereo_i_extended_disp: false
    stereo_i_height: 480
    stereo_i_low_bandwidth: false
    stereo_i_low_bandwidth_quality: 50
    stereo_i_lr_check: true
    stereo_i_lrc_threshold: 10
    stereo_i_max_q_size: 30
    stereo_i_rectify_edge_fill_color: 0
    stereo_i_spatial_filter_alpha: 0.5
    stereo_i_spatial_filter_delta: 20
    stereo_i_spatial_filter_hole_filling_radius: 2
    stereo_i_spatial_filter_iterations: 1
    stereo_i_stereo_conf_threshold: 255
    stereo_i_temporal_filter_alpha: 0.4
    stereo_i_temporal_filter_delta: 20
    stereo_i_temporal_filter_persistency: VALID_2_IN_LAST_4
    stereo_i_threshold_filter_max_range: 15000
    stereo_i_threshold_filter_min_range: 400
    stereo_i_width: 640

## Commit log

2023-04-11 It walks
    [hardware.yaml]
2023-04-12 Fixed angle calculations and it kind of walks
    [servo_interface.py]
2023-04-14 Increased publish rate for servo signals for smoother movement
2023-04-16 Re-added description
    [B_cover.stl, F_cover.stl, F_cover_orig.stl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]
2023-04-17 Starting dockerizing for jetson
2023-04-17 Progress on docker for jetson nano
2023-04-19 Runs on Noetic Jetson 20.04
2023-04-19 Working toawads direct I2C
2023-04-19 Working on pwm controller
2023-04-19 Working on servos
2023-04-21 Added servo_connected arg
2023-04-27 Metal servohorn hip
    [Circuitry_Mountingplate_jetson_nano.FCStd, Outer_Shoulder_round_servohorn.FCStd, Outer_Shoulder_round_servohorn.stl]
2023-04-27 Added third party STLs
    [Limb_Top_Shell_with_BB_hole.stl, Rear_Cover_Plate_Medium.stl, Rear_Cover_Shell_Medium.FCStd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]
2023-05-03 Added base calibration script
2023-05-04 Lengthened chassis and added modular board carrier
    [Chassis_Side_longer.FCStd, Chassis_Side_longer.stl, Circuitry_Mountingplate_jetson_nano.FCStd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]
2023-05-05 Moved IMU Higher up to avoid Jetson
    [circuit_carrier.FCStd]
2023-05-05 Lengthened Bottom Cover 25mm
    [Bottom_Cover_Split_Front.FCStd, Bottom_Cover_Split_Front.stl]
2023-05-11 Extended bottom cover and added lidar mount
    [Bottom_Cover_Split_Front.FCStd, hitachi_lg_lidar_mount.FCStd, hitachi_lg_lidar_mount.stl]
2023-05-11 Extended top cover
    [Top_Cover.FCStd]
2023-05-11 Added fan and lidar
    [Top_Cover.FCStd, top_cover.stl]
2023-05-12 Sliced top cover in half
    [top_cover_back.stl, top_cover_front.stl]
2023-05-12 raspberry pi camera mount
    [Top_Cover.FCStd, cameramount_rpi.FCStd, cameramount_rpi.stl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]
2023-05-15 Updated rpi camera mount
    [cameramount_rpi.FCStd, cameramount_rpi.stl]
2023-05-15 Updated circuit carrier
    [Front_Cover_oakdlite.FCStd, circuit_carrier.FCStd]
2023-05-15 forgot screw holes
    [circuit_carrier.FCStd]
2023-05-15 adding oak d lite camera head
    [Front_Cover_oakdlite.FCStd]
2023-05-15 made faceplate modular for oak d lite
    [Front_Cover_oakdlite.FCStd, Front_Cover_oakdlite.stl]
2023-05-16 added oakdlite plate/mount
    [cameramount_rpi.FCStd, cameramount_rpi.stl, circuit_carrier.FCStd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]
2023-05-16 Updating oak d lite plate
    [Front_Cover_oakdlite.FCStd, oakdlite_plate.FCStd]
2023-05-16 Updated plate
    [oakdlite_plate.FCStd]
2023-05-17 Made curses interfae for servo calibration
2023-05-17 Updated calibration values
2023-05-17 Write correct yaml file
    [servo_calibration.py, servo_interface.py]
2023-05-20 Moved mounting holes for camera
    [oakdlite_plate.FCStd]
2023-05-23 Working on urdf
    [fennee.urdf, fennee.xacro, stairs.urdf.xacro]
2023-05-24 Added oak d lite camera to urdf
    [fennee.urdf, fennee.xacro]
2023-05-24 Starting to add camera
2023-05-24 Addiong camera
2023-05-25 Camera working somewhat
2023-05-26 Adding laser
2023-05-27 Fixing link for foxglove
    [fennee.urdf, fennee.xacro]
2023-05-29 Fixed camera orientation
    [fennee.urdf, fennee.xacro]
2023-05-29 reversed lidar
    [fennee.urdf, fennee.xacro]
2023-05-29 Reversed camera again
    [fennee.urdf, fennee.xacro]
2023-05-29 Rotated lidar
    [fennee.urdf, fennee.xacro]
2023-05-30 Rotated jetson 90 degrees to get at usb ports
    [circuit_carrier.FCStd]
2023-05-30 Rotate camera again
    [fennee.urdf, fennee.xacro]
2023-05-31 Fixing camera yaw again
    [fennee.urdf, fennee.xacro]
2023-05-31 Fixing jetson nano mount
    [circuit_carrier.FCStd]
2023-05-31 Forgot threads
    [circuit_carrier.FCStd]
2023-06-01 Fixing servo_controller
2023-06-01 Updated IMU from camera
    [fennee.urdf, fennee.xacro]
2023-06-02 Working on imu
    [fennee.urdf]
2023-06-08 Finally got slam working
    [fennee.urdf, fennee.xacro]
2023-06-08 Generated urdf
    [fennee.urdf, fennee.xacro]
2023-06-08 Added new servo arm for round servohorn
    [Limb_Servohorn_Mount_long_v4.FCStd, Limb_Servohorn_Mount_long_v4.stl, Outer_Shoulder_round_servohorn.FCStd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]
2023-06-08 Slight tweaks to servohorn
    [Limb_Servohorn_Mount_long_v4.FCStd, Limb_Servohorn_Mount_long_v4.stl]
2023-06-09 Moved servo disk a little deeper and reduced hole fillet
    [Limb_Servohorn_Mount_long_v4.FCStd, Limb_Servohorn_Mount_long_v4.stl]
2023-06-09 Make shallower so screws don't stick out
    [Limb_Servohorn_Mount_long_v4.FCStd, Limb_Servohorn_Mount_long_v4.stl]
2023-06-12 Making calibration script automated
    [servos_calibration.yaml]
2023-06-12 Added extra holes for voltage led display
    [Outer_Shoulder_round_servohorn.FCStd, Rear_Cover_Plate_Medium.stl, Rear_Cover_Shell_Medium.FCStd]
2023-06-12 Fixing calibrator direction
    [servos_calibration.yaml]
2023-06-16 Bigger servos for wrist
    [Chassis_Side_longer.FCStd, Chassis_Side_longer.stl, Wrist.FCStd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]
2023-06-16 Fix again. might be wrong part
    [Wrist.FCStd, Wrist.stl]
2023-06-21 Added config for lidar serial port
    [servos_calibration.yaml]
